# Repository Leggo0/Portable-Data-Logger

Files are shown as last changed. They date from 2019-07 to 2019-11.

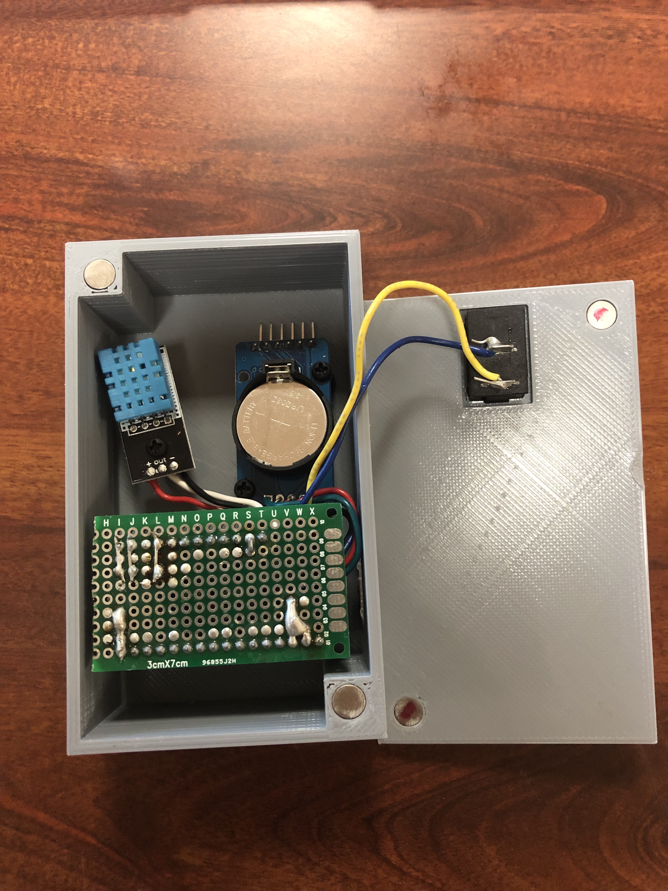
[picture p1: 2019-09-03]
DataLogger_Image2.jpeg

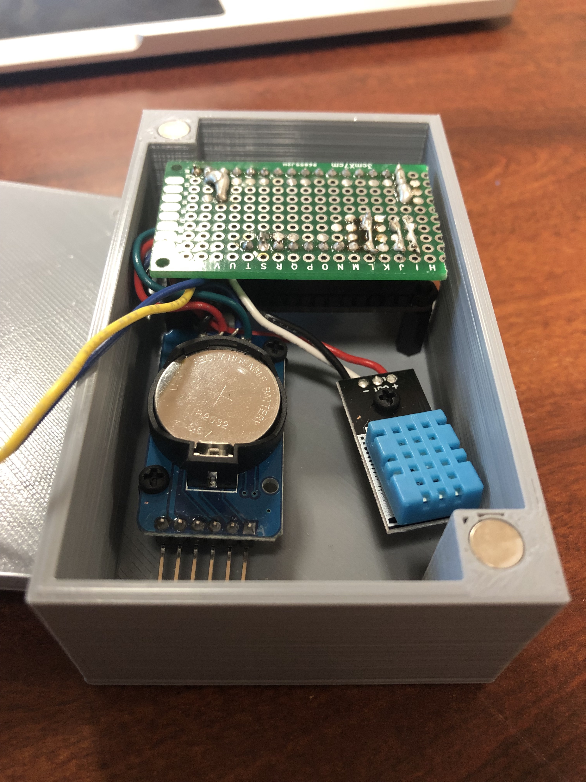
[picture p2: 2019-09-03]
DataLogger_Image3.jpeg

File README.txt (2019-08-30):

Written by Austin Salois
Summer 2019
For: Fairfield Osborn Preserve and Chris Halle
Purpose: Create a simple temperatre and humidity data logger
to be used when studying microclimates on the preserve. 
The logger should take accurate data readings, alone with
an accurate time of when the data was taken for future proccessing

There is 2 .ino files associated with this project.
Use the "debug" program when building and testing. 
This file has the same functionality as the deployed file,
the only differences are it opens a serial connection for debugging
and it takes data every second rather than every 60 seconds

The case was designed to be 3D printed and includes 
both a Box and a Lid.
These are designed to be heald together with 1/4 x 1/16 in magnets.
There is a place for a toggle swith on the top as well.
The components used use M2 screws. Since they are not
often found in store, this: https://www.adafruit.com/product/3299
set from Adafruit should be ordered. It will also be included
in the bill of materials.

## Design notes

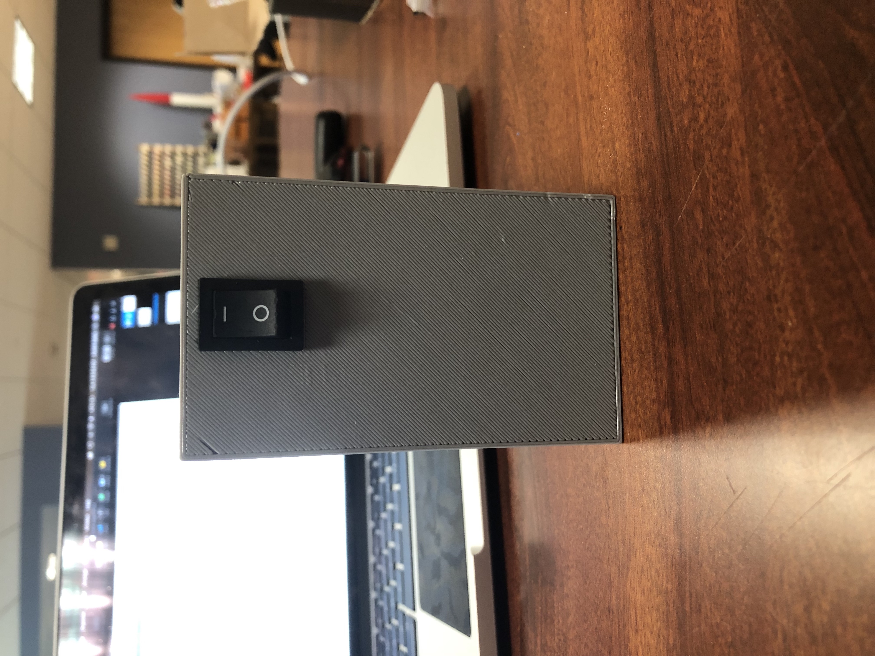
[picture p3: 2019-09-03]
DataLogger_Image1.jpeg

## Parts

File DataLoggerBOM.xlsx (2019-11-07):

DataLoggerBOM
Data Logger Bill of Materials w/o Battery
Item | Quantity | Price per Unit | Source
Adafruit Feather 32u4 Adalogger | 3 | $21.95 | Adafruit
M2 Screw Set, Black Nylon | 1 | $16.95 | Adafruit
Temp Sensor Pack | 1 | $10.49 | Amazon
Real Time Clock | 3 | $3.99 | Amazon
Micro SD Card | 3 | $5.79 | Amazon
SPST ON/OFF Rocker Switch Pack | 1 | $5.99 | Amazon
Total | $105.68

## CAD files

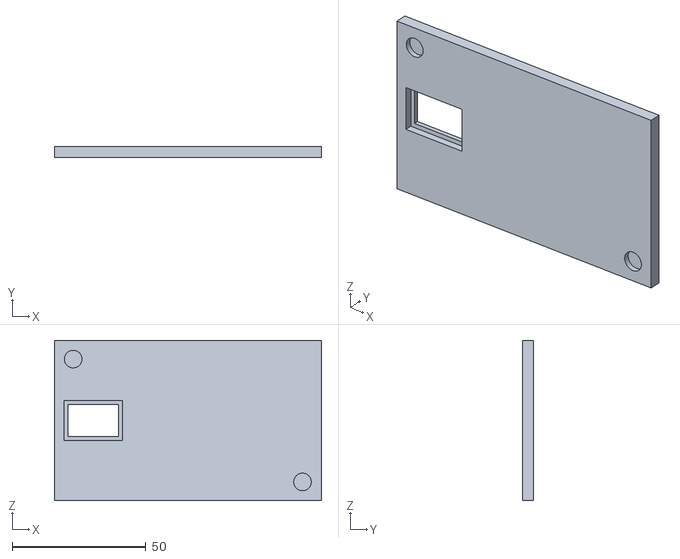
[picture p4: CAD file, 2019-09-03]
DataLoggerLid.stl
100.0 x 4.00 x 60.0

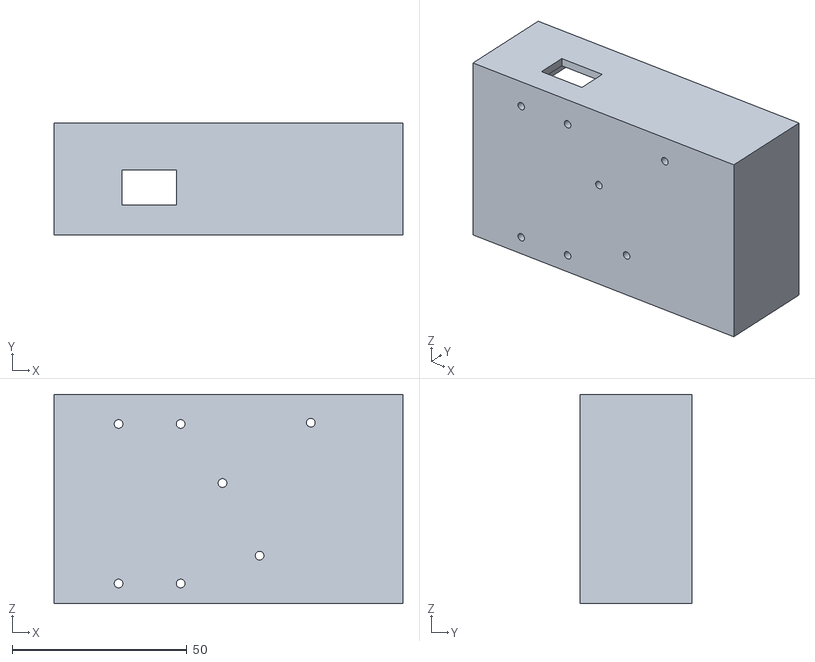
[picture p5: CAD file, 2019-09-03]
DataLoggerBox.stl
100.0 x 32.0 x 60.0

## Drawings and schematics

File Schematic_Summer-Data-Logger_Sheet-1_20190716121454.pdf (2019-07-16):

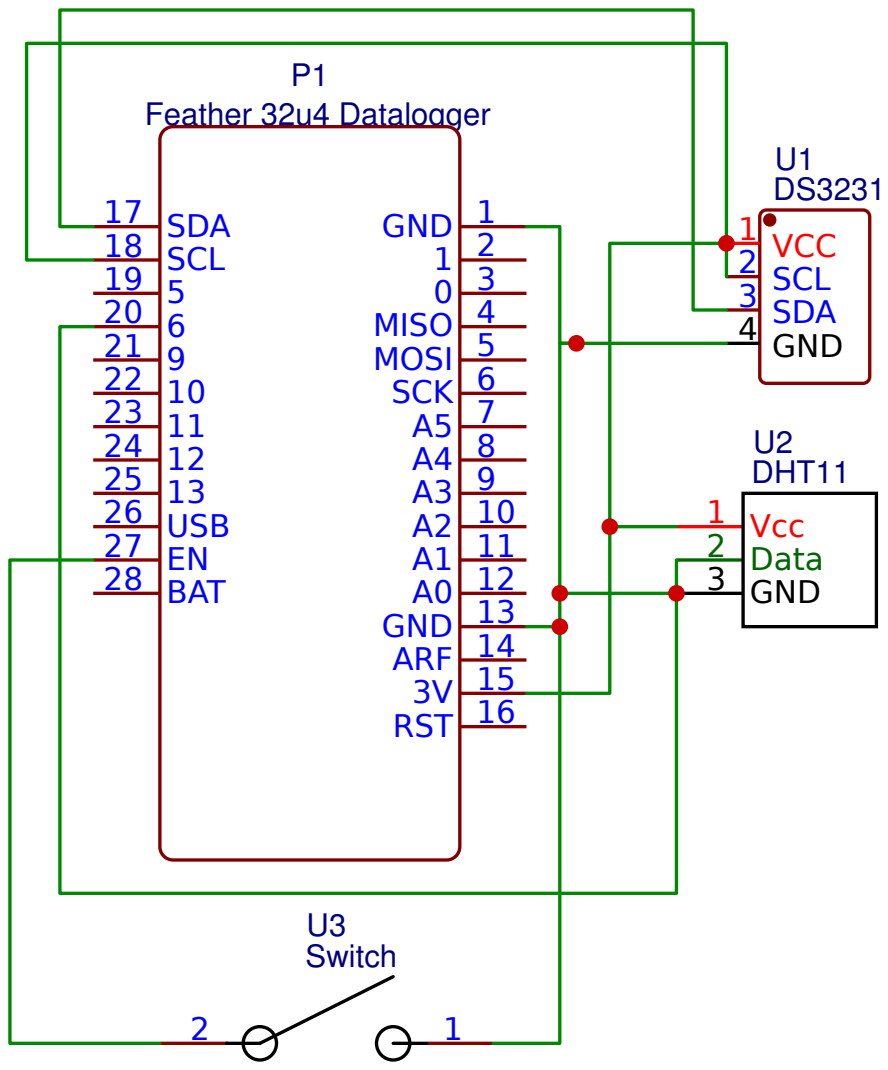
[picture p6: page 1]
TITLE:; Portable Data Logger; REV: 1.0; Date:; Sheet: 1/1; Feather 32u4 Datalogger; GND 1 1 2 0 3 MISO 4 MOSI 5 SCK 6 A5 7 A4 8 A3 9 A2 10 A1 11 A0 12 GND 13 ARF 14 3V 15 RST 16; SDA 17 SCL 18 5 19 6 20 9 21 10 22 11 23 12 24 13 25 USB 26 EN 27 BAT 28; VCC 1 SCL 2 SDA 3 GND 4; DHT11; Vcc 1 Data 2 GND 3; Switch

Company: Sonoma State Engineering

Drawn By: Austin Salois

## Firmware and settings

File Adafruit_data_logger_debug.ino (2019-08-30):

/*
 * Written by Austin Salois
 * Summer 2019
 * For: Fairfield Osborn Preserve and Chris Halle
 * Purpose: Create a simple temperatre and humidity data logger
 * to be used when studying microclimates on the preserve. 
 * The logger should take accurate data readings, alone with
 * an accurate time of when the data was taken for future proccessing
 * 
 * https://github.com/Leggo0/Portable-Data-Logger
 */


//Includes
#include "SdFat.h"
#include <SPI.h>
#include "RTClib.h"
#include <DHT.h>
#include <DHT_U.h>

//Defines
#define DHTPIN 6
#define DHTTYPE DHT11
#define SD_CS_PIN 4


SdFat SD;
DHT dht(DHTPIN, DHTTYPE);

RTC_DS3231 rtc;



//Creating blank file name
String FILENAME;

const String header = "Date, Time(24Hr), Temp(C), Humidity"; //Header for file, does not change
void setup() 
{
  Serial.begin(9600);
  while (!Serial) {
    ; // wait for serial port to connect. Needed for native USB port only
  }
  
  dht.begin();
  if (!SD.begin(SD_CS_PIN)) {
    Serial.println("initialization failed!");
    return;
  }
  Serial.println("initialization done.");
  //Create filename from date read from RTC
  Serial.print("Creating File Name");
  
  DateTime now = rtc.now(); //We need to get the data to create the file name
  int month =  now.month();
  int day = now.day();
  int hour = now.hour();
  int minute = now.minute();
  //Create the file name
  FILENAME = String(now.month()) +  "-" + String(now.day()) + "@" + String(now.hour()) + "-" + String(now.minute()) + ".csv";
  
  Serial.print("The file name is: ");
  Serial.println(FILENAME);
  File dataFile = SD.open(FILENAME, FILE_WRITE); //Push header to file
  if (dataFile)
  {
    Serial.println("File first open");
    dataFile.println(header);
    dataFile.close();
  }
  else
  {
    Serial.println("Unable to initialize file");
  }
}

void loop() 
{
  //Making string to push to file
  String Push = "";
  DateTime now = rtc.now(); //Get current time and date

  String Date = String(now.month()) + "/" + String(now.day()) + "/" + String(now.year()); //Create the Date string
  String Time = String(now.hour()) + ":" + String(now.minute()) + ":" + String(now.second()); //Create the Time string

  float Humidity = dht.readHumidity(); //Read the humidity
  float Temp = dht.readTemperature(); //Read the temperature
  
  Push = Date + "," + Time + ","; //Create beginning of string
  Serial.print(Push);
  Serial.print(Temp); //Push the tempeature
  Serial.print(","); //Push the seperator
  Serial.print(Humidity); //Push the humidity
  Serial.println("\n"); //Push line deliminator

  
  File dataFile = SD.open(FILENAME, FILE_WRITE); //Open file on SD card
  if (dataFile){
    dataFile.print(Push); //Push the tempeature
    dataFile.print(Temp); //Push the seperator
    dataFile.print(","); //Push the seperator
    dataFile.print(Humidity); //Push the humidity
    dataFile.print("\n"); //Push line deliminator
    Serial.print("Data pushed to SD Card\n");
    dataFile.close(); //Close the file
  }
  else{
    Serial.println("Error opening file");
  }
  

  delay(1000); //Wait 1 minute
  
  

}
